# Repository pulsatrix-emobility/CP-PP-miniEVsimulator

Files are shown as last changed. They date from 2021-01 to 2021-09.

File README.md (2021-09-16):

# CP-PP-miniEVsimulator
This is a small PBC to simulate the CP signal of an electric vehicle (EV) and the PP signal of the IEC 62196 type 2 or SAE J1772 type 1 plug according to IEC 61851.

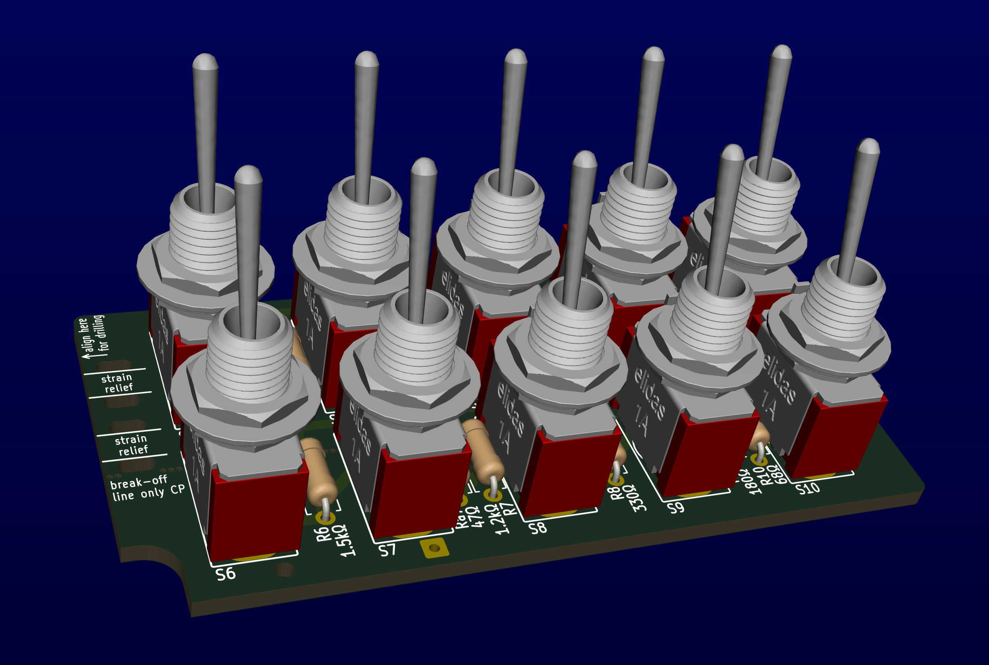
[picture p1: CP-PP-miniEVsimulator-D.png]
CP-PP-EV-simulator inclined


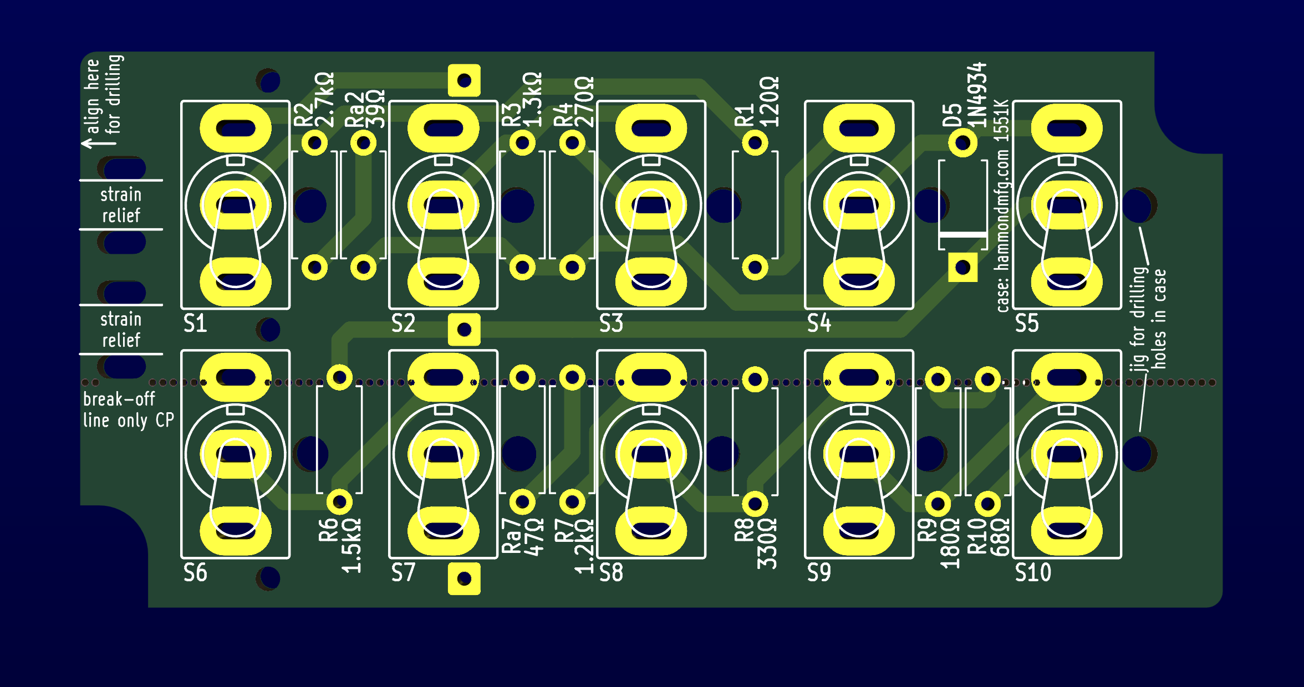
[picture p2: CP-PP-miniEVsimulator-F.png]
CP-PP-EV-simulator front


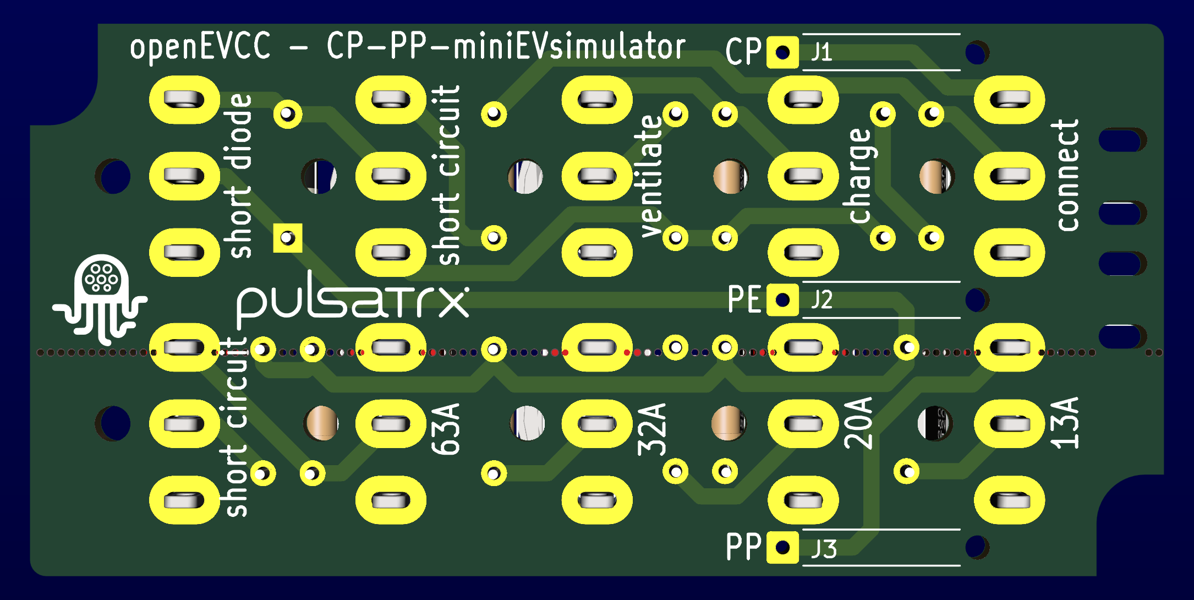
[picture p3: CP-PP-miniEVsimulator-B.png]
CP-PP-EV-simulator back


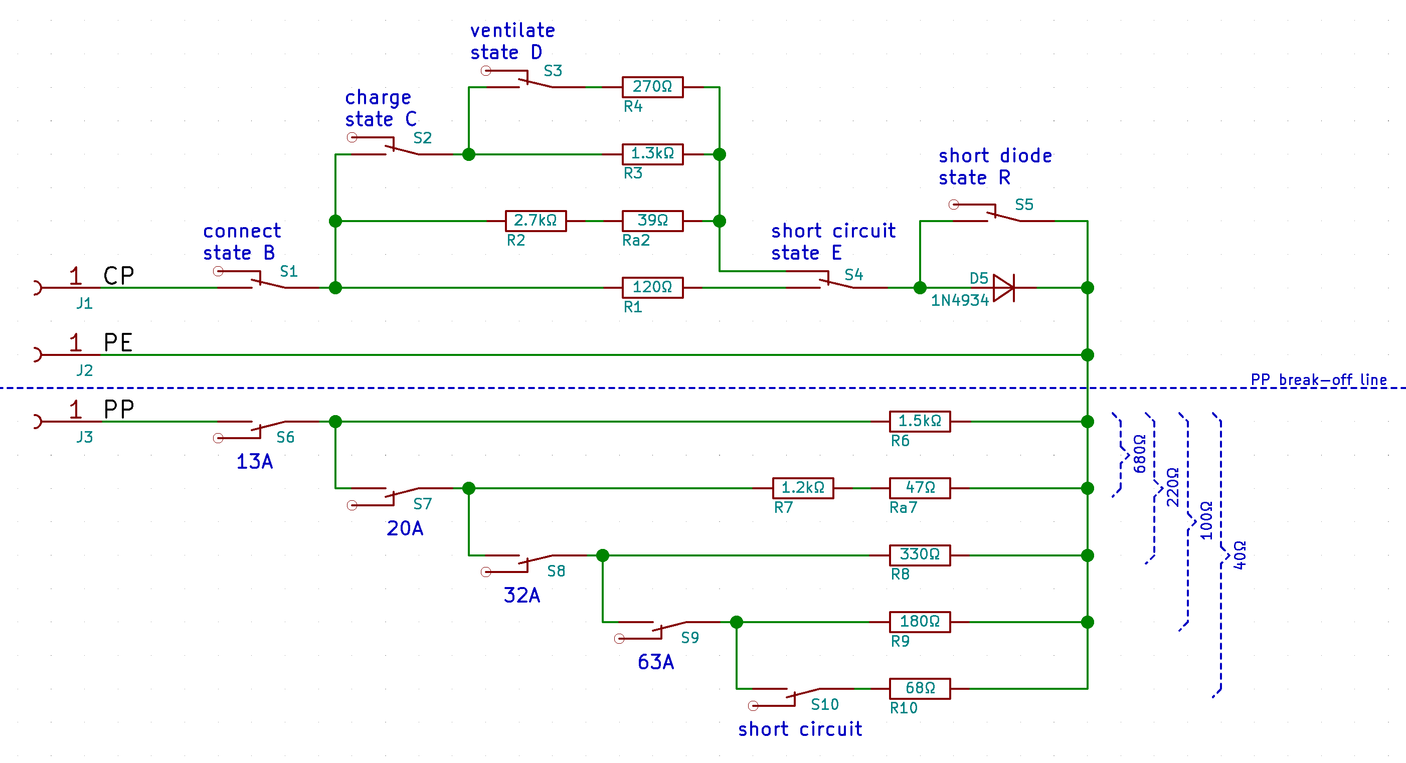
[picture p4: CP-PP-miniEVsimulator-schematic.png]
CP-PP-EV-simulator schematic


[PDF Schematic](CP-PP-miniEVsimulator.pdf)

## CP signal
The EV shows different resistor values to signal its status.
5 miniature toggle switches allow to simulate the CP signal for following EV states:
| status | S1  | S2  | S3  | S4  | S5  | description |
| --- | --- | --- | --- | --- | --- | --- |
| A | off |  x  |  x  |  x  |  x  | EV disconnected |
| B | on  | off |  x  | off | off | EV connected |
| C | on  | on  | off | off | off | charging request |
| D | on  | on  | on  | off | off | ventilation request |
| E | on  |  x  |  x  |  on | off | short circuit |
| R | on  |  x  |  x  |  x  | on  | diode shorted |

## PP signal
Different resistor values in the connector on each side fo the charging cable signal the EVSE and the EV the ampacity of the cable, to avoid an overload condition.
Another 5 toggles switches allow to simulate the PP signal for the following cable ampacities:
| ampacity | S6  | S7  | S8  | S9  | S10 |
| --- | ----| --- | --- | --- | --- |
| disconnected | off |  x  |  x  |  x  |  x  |
| 13A | on  | off |  x  |  x  |  x  |
| 20A | on  | on  | off |  x  |  x  |
| 32A | on  | on  | on  | off |  x  |
| 63A | on  | on  | on  | on  | off |
| short | on  | on  | on  | on  | on  |

The PP part of the PCB can be broken off to reduce PCB size when the PP simulation is not nedded.

### Bill of materials
| designator | value   |
| --- | --- |
| R1 | 120Ω  |
| R2 |  2.7kΩ  |
| Ra2 | 39Ω  |
| R3 |  1.3kΩ  |
| R4 | 270Ω  |
| D5 | 1N4934  |
| R6 |  1.5kΩ  |
| R7 |  1.2kΩ  |
| Ra7 | 47Ω  |
| R8 | 330Ω  |
| R9 | 180Ω  |
| R10 | 68Ω  |
| S1,S2,S3,S4,S5,S6,S7,S8,S9,S10 | miniature Toggle switch |
| case | hammond 1551K |
| | 2mm zip tie  |

### Simulation of the simulator
The simulator can be simulated here: https://tra.fo/cp-simulation

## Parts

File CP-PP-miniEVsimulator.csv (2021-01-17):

Comment | Designator | Footprint | LCSC
1N4934 | D5 | Diode_THT:D_A-405_P7.62mm_Horizontal
Conn_01x01_Female | J1,J2,J3 | Connector_Wire:SolderWire-0.25sqmm_1x01_D0.65mm_OD2mm_Relief
120Ω | R1 | Resistor_THT:R_Axial_DIN0207_L6.3mm_D2.5mm_P7.62mm_Horizontal
68Ω | R10 | Resistor_THT:R_Axial_DIN0207_L6.3mm_D2.5mm_P7.62mm_Horizontal
2.7kΩ | R2 | Resistor_THT:R_Axial_DIN0207_L6.3mm_D2.5mm_P7.62mm_Horizontal
1.3kΩ | R3 | Resistor_THT:R_Axial_DIN0207_L6.3mm_D2.5mm_P7.62mm_Horizontal
270Ω | R4 | Resistor_THT:R_Axial_DIN0207_L6.3mm_D2.5mm_P7.62mm_Horizontal
1.5kΩ | R6 | Resistor_THT:R_Axial_DIN0207_L6.3mm_D2.5mm_P7.62mm_Horizontal
1.2kΩ | R7 | Resistor_THT:R_Axial_DIN0207_L6.3mm_D2.5mm_P7.62mm_Horizontal
330Ω | R8 | Resistor_THT:R_Axial_DIN0207_L6.3mm_D2.5mm_P7.62mm_Horizontal
180Ω | R9 | Resistor_THT:R_Axial_DIN0207_L6.3mm_D2.5mm_P7.62mm_Horizontal
39Ω | Ra2 | Resistor_THT:R_Axial_DIN0207_L6.3mm_D2.5mm_P7.62mm_Horizontal
47Ω | Ra7 | Resistor_THT:R_Axial_DIN0207_L6.3mm_D2.5mm_P7.62mm_Horizontal
Switch_SPDT | S1,S2,S3,S4,S5,S6,S7,S8,S9,S10 | _sauttefk:miniatureToggleSwitch_12.7x6.6

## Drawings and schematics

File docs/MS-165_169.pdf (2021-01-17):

M6

P

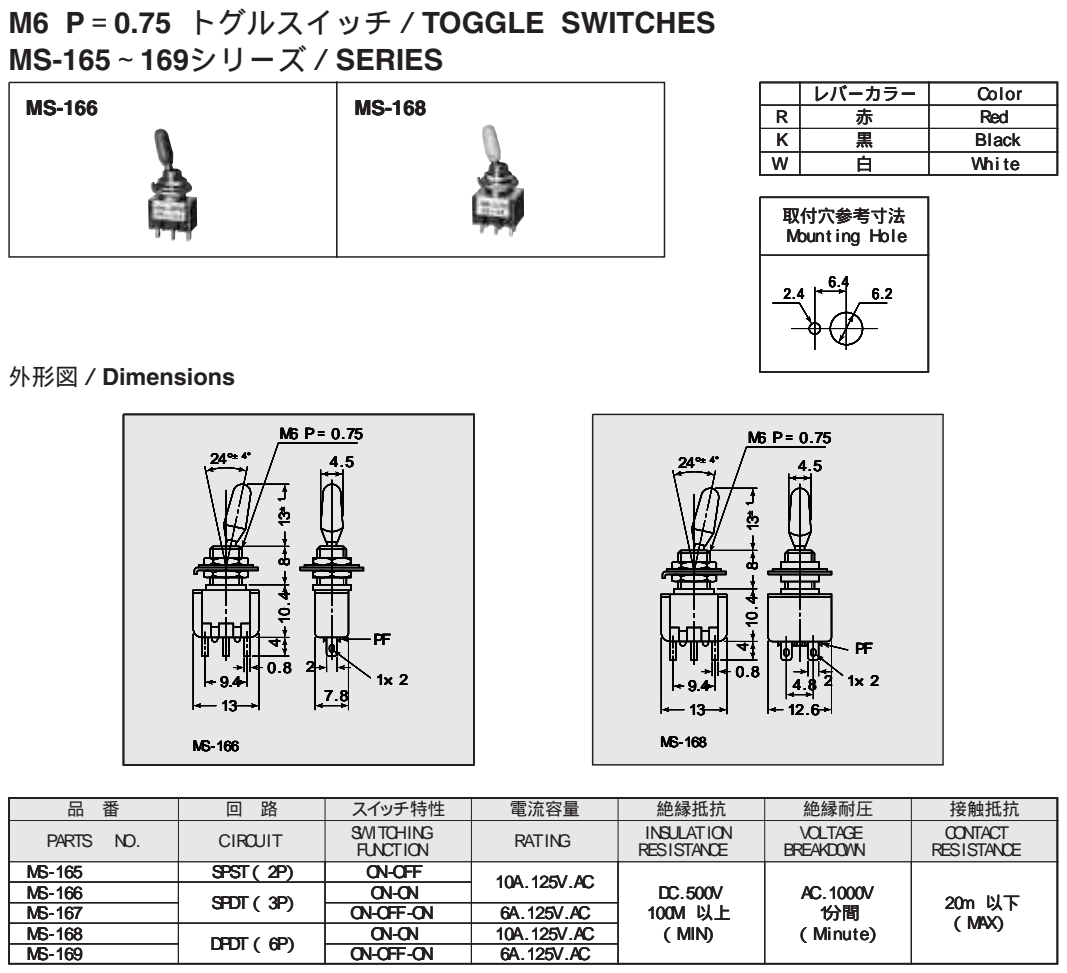
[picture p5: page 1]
＝0.75 トグルスイッチ／; TOGGLE SWITCHES; ～169シリーズ／SERIES; 外形図／Dimensions; ッチ特性; 電流容量; 絶縁抵抗; 絶縁耐圧; 接触抵抗; レバーカラー 赤黒白

取付穴参考寸法 取付穴参考寸法

（ （ （ （ ） ） ） ） | Ω以上 Ω以上 Ω以上 Ω以上 （ （ （ （ ） ） ） ） | 分間 分間 分間 分間 （ （ （ （ ） ） ） ） | Ω以下 Ω以下 Ω以下 Ω以下 （ （ （ （ ） ） ） ）
（ （ （ （ ） ） ） ）

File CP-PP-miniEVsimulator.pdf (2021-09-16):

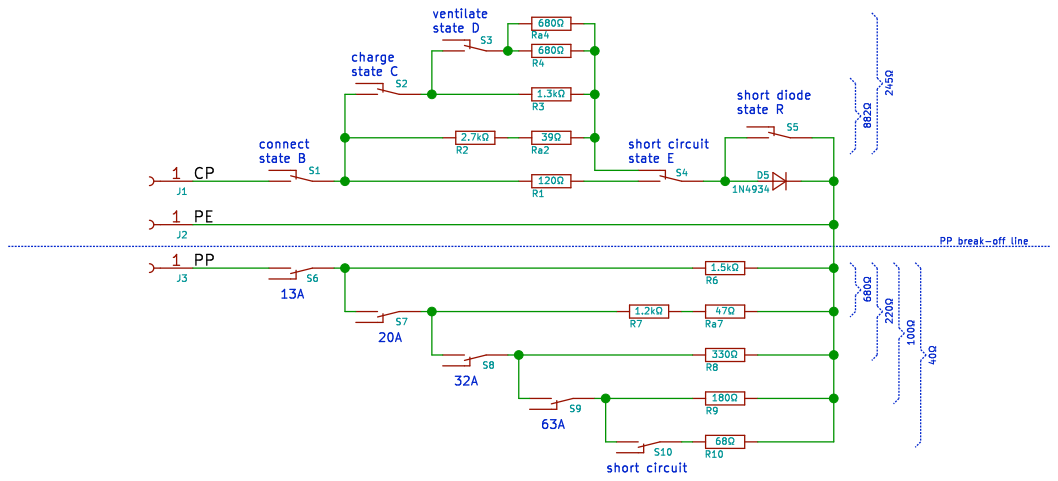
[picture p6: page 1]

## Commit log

2021-01-17 small changes, revived README
    [CP-PP-miniEVsimulator.kicad_pcb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]
2021-01-17 front silkscreen changes
    [CP-PP-miniEVsimulator-F_SilkS.gbr]
2021-09-16 cutouts mirrored
    [CP-PP-miniEVsimulator-B_Cu.gbr, CP-PP-miniEVsimulator-B_Mask.gbr, CP-PP-miniEVsimulator-B_SilkS.gbr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]
